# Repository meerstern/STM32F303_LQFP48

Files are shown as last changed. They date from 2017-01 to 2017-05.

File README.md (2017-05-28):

# STM32F303_LQFP48

The Converter board of Kicad Files for STM32F303-LQFP48

STM32F303 LQFP48を2.54mmピッチへ変換します。  
5列両側の一般的なブレッドボードで両側に1つ空きが出るサイズです。  
Nucleo等の評価ボードが発売されていない48ピンICの変換基板です。  
32ピンではRAMサイズやピン数が足りないが、64ピンでは多すぎるという方にお勧めです。  
※mbedには対応していません。 

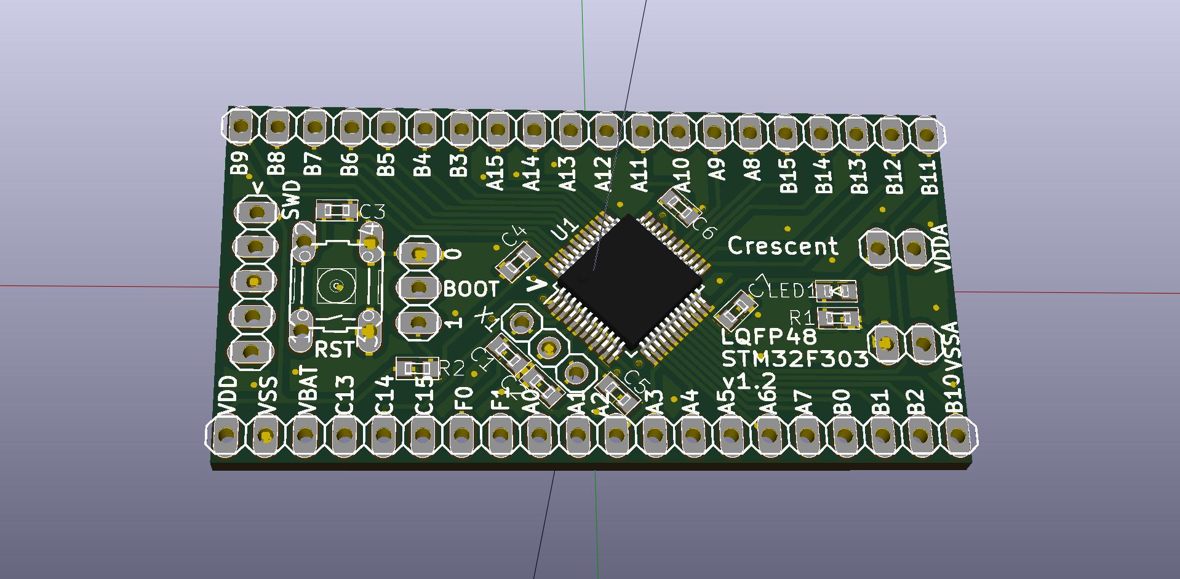
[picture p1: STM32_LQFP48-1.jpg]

 
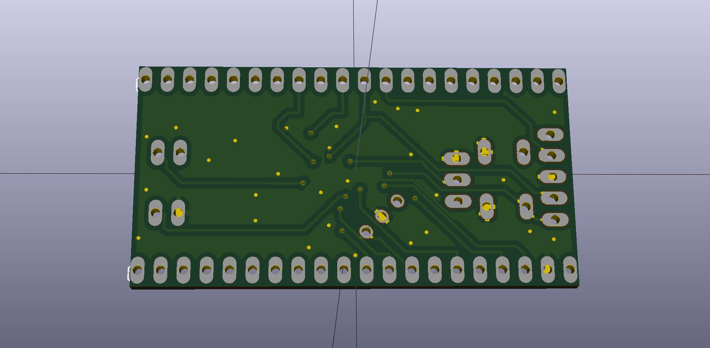
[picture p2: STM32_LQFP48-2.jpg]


## 仕様
  * MPU48ピンの全ピンにアクセス可能です。
  * 両側それぞれ20ピン、計40ピンです。
  * VDD及びVDDはそれぞれ1つのピンにまとめています。
  * アナログピンはVSSA、VDDAをジャンパするとVDDとVSSからそれぞれ供給されます。
  * VDDへ電源を供給するとLED1が点灯します。
  * SWDピンが出ているため、STLinkで接続して書き込みします。
  * SWDピンはNucleo等のSTLinkのピン配置と同じ順序です。
  * BOOT0のピンヘッダがあり、簡単にモード切り替え可能です。
  * タクトスイッチを取り付けることでリセットボタンが実装可能です。

## 使用可能MPU
  * STM32F303C8XX ROM64KB,  RAM12KB  [Digikey Link][1]
  * STM32F303CCXX ROM256KB, RAM40KB  [Digikey Link][3]
  ※上記の全MPUで動作確認している訳ではありません。  

[1]: http://www.digikey.jp/product-detail/ja/stmicroelectronics/STM32F303C8T6/497-15198-ND/5051326 "*1"
[3]: http://www.digikey.jp/product-detail/ja/stmicroelectronics/STM32F303CCT6/497-13318-ND/3660423 "*3"

## 書き込み方法/使用方法
  * アナログピンはVSSA、VDDAをジャンパさせます。
  * BOOTピンを0へセットします。
  * SWDピンが出ているため、STLinkで接続して書き込みします。
  * SWDピンはNucleo等のSTLinkのピン配置と同じ順序です。
  * 電源を供給し、NucleoやSTLinkV2プログラマ等を使用してSTLinkUtility等から書き込んでください。  
  
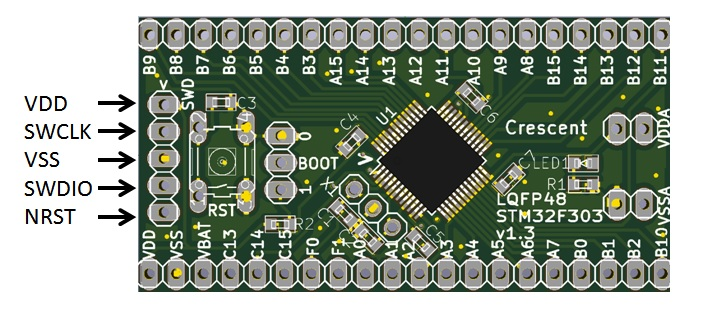
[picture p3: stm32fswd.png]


License - MIT

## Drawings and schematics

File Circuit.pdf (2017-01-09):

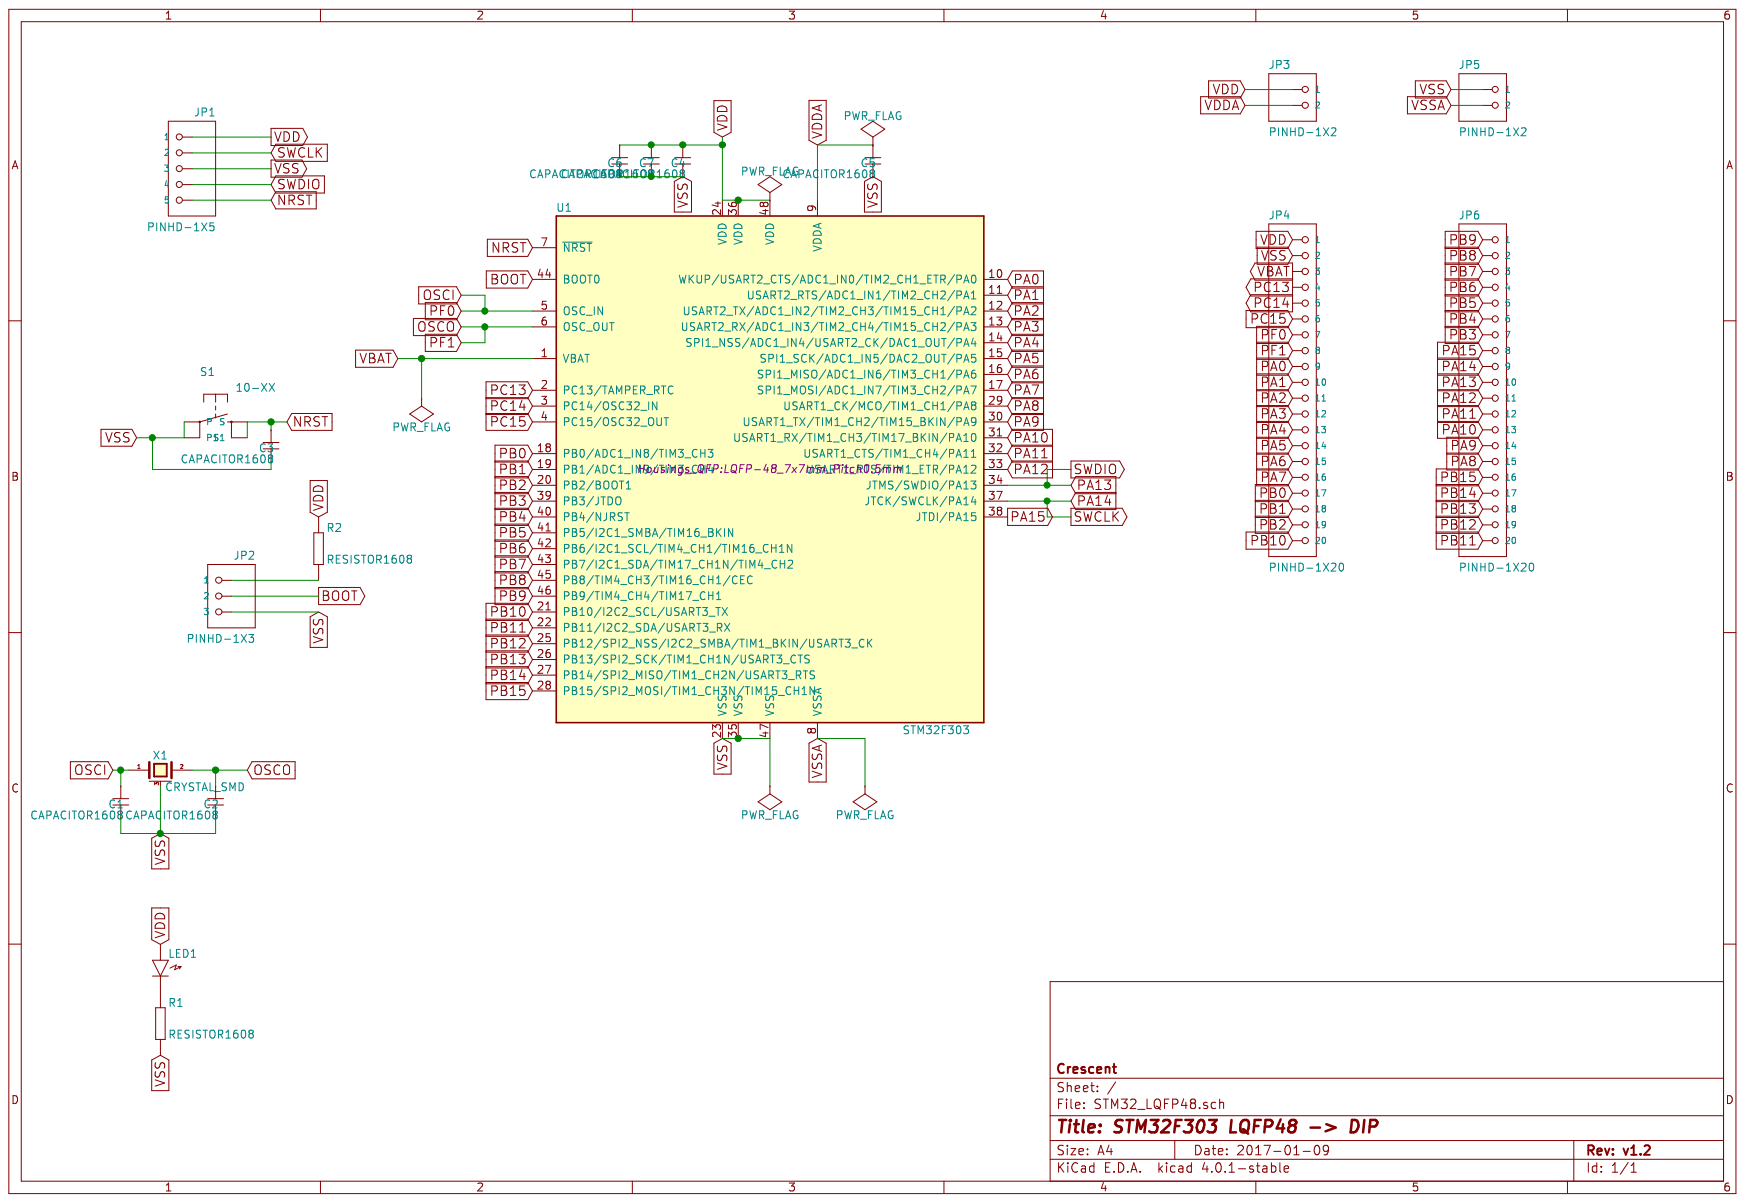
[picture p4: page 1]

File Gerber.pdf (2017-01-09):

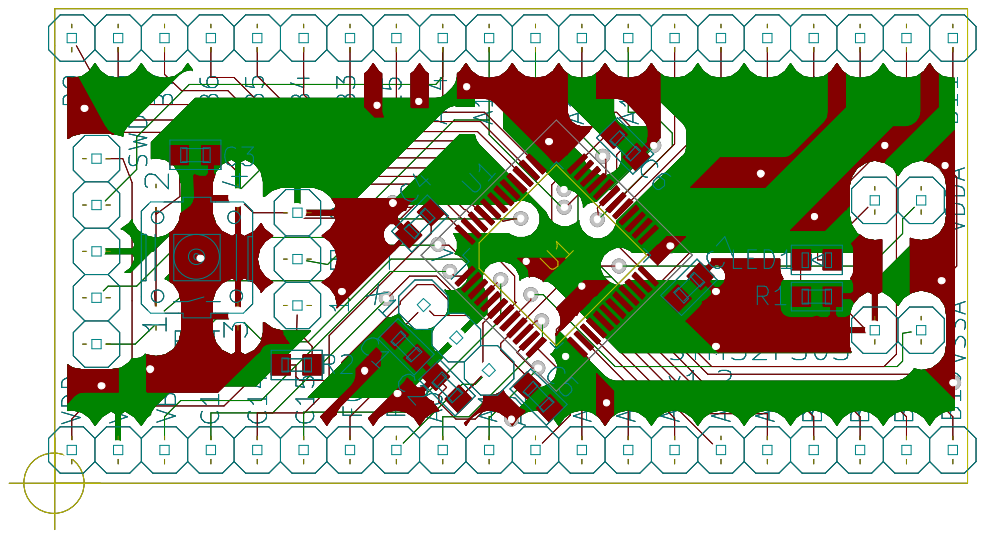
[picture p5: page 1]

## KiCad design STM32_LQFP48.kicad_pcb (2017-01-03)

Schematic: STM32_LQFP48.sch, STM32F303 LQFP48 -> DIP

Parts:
C1, C2, C3, C4, C5, C6, C7: CAPACITOR1608; generic-SMD1608
JP1: PINHD-1X5; pinhead-1X05
JP2: PINHD-1X3; pinhead-1X03
JP3, JP5: PINHD-1X2; pinhead-1X02
JP4, JP6: PINHD-1X20; pinhead-1X20
LED1: LED1608; generic-LED1608
R1, R2: RESISTOR1608; generic-SMD1608
S1: 10-XX; switch-omron-B3F-10XX
U1: STM32F303; LQFP-48_7x7mm_Pitch0.5mm
X1: CRYSTAL_SMD; pinhead-1X03

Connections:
BOOT: JP2.2, U1.44 (BOOT0)
NRST: C3.1, JP1.5, S1.1, S1.2, U1.7 (~NRST)
unnamed: JP2.1, R2.2
unnamed: LED1.K, R1.1
OSCI: C1.1, JP4.7, U1.5 (OSC_IN), X1.1
OSCO: C2.1, JP4.8, U1.6 (OSC_OUT), X1.2
PA0: JP4.9, U1.10 (WKUP/USART2_CTS/ADC1_IN0/TIM2_CH1_ETR/P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)
PA1: JP4.10, U1.11 (USART2_RTS/ADC1_IN1/TIM2_CH2/PA1)
PA2: JP4.11, U1.12 (USART2_TX/ADC1_IN2/TIM2_CH3/TIM15_CH1/P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)
PA3: JP4.12, U1.13 (USART2_RX/ADC1_IN3/TIM2_CH4/TIM15_CH2/P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)
PA4: JP4.13, U1.14 (SPI1_NSS/ADC1_IN4/USART2_CK/DAC1_OUT/PA4)
PA5: JP4.14, U1.15 (SPI1_SCK/ADC1_IN5/DAC2_OUT/PA5)
PA6: JP4.15, U1.16 (SPI1_MISO/ADC1_IN6/TIM3_CH1/PA6)
PA7: JP4.16, U1.17 (SPI1_MOSI/ADC1_IN7/TIM3_CH2/PA7)
PA8: JP6.15, U1.29 (USART1_CK/MCO/TIM1_CH1/PA8)
PA9: JP6.14, U1.30 (USART1_TX/TIM1_CH2/TIM15_BKIN/PA9)
PA10: JP6.13, U1.31 (USART1_RX/TIM1_CH3/TIM17_BKIN/PA10)
PA11: JP6.12, U1.32 (USART1_CTS/TIM1_CH4/PA11)
PA12: JP6.11, U1.33 (USART1_RTS/TIM1_ETR/PA12)
PA13: JP1.4, JP6.10, U1.34 (JTMS/SWDIO/PA13)
PA14: JP1.2, JP6.9, U1.37 (JTCK/SWCLK/PA14)
PA15: JP6.8, U1.38 (JTDI/PA15)
PB0: JP4.17, U1.18 (PB0/ADC1_IN8/TIM3_CH3)
PB1: JP4.18, U1.19 (PB1/ADC1_IN9/TIM3_CH4)
PB2: JP4.19, U1.20 (PB2/BOOT1)
PB3: JP6.7, U1.39 (PB3/JTDO)
PB4: JP6.6, U1.40 (PB4/NJRST)
PB5: JP6.5, U1.41 (PB5/I2C1_SMBA/TIM16_BKIN)
PB6: JP6.4, U1.42 (PB6/I2C1_SCL/TIM4_CH1/TIM16_CH1N)
PB7: JP6.3, U1.43 (PB7/I2C1_SDA/TIM17_CH1N/TIM4_CH2)
PB8: JP6.2, U1.45 (PB8/TIM4_CH3/TIM16_CH1/CEC)
PB9: JP6.1, U1.46 (PB9/TIM4_CH4/TIM17_CH1)
PB10: JP4.20, U1.21 (PB10/I2C2_SCL/USART3_TX)
PB11: JP6.20, U1.22 (PB11/I2C2_SDA/USART3_RX)
PB12: JP6.19, U1.25 (PB12/SPI2_NSS/I2C2_SMBA/TIM1_BKIN/USART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)
PB13: JP6.18, U1.26 (PB13/SPI2_SCK/TIM1_CH1N/USART3_CTS)
PB14: JP6.17, U1.27 (PB14/SPI2_MISO/TIM1_CH2N/USART3_RTS)
PB15: JP6.16, U1.28 (PB15/SPI2_MOSI/TIM1_CH3N/TIM15_CH1N)
PC13: JP4.4, U1.2 (PC13/TAMPER_RTC)
PC14: JP4.5, U1.3 (PC14/OSC32_IN)
PC15: JP4.6, U1.4 (PC15/OSC32_OUT)
VBAT: JP4.3, U1.1 (VBAT)
VDD: C4.1, C6.1, C7.1, JP1.1, JP3.1, JP4.1, LED1.A, R2.1, U1.24 (VDD), U1.36 (VDD), U1.48 (VDD)
VDDA: C5.1, JP3.2, U1.9 (VDDA)
VSS: C1.2, C2.2, C3.2, C4.2, C5.2, C6.2, C7.2, JP1.3, JP2.3, JP4.2, JP5.1, R1.2, S1.3, S1.4, U1.23 (VSS), U1.35 (VSS), U1.47 (VSS), X1.3
VSSA: JP5.2, U1.8 (VSSA)

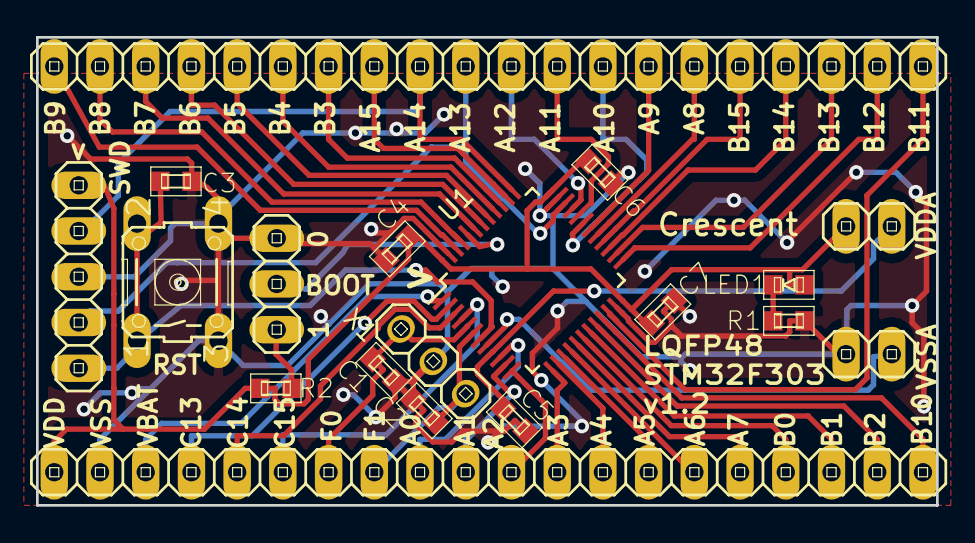
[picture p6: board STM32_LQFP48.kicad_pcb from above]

Board: 2 copper layers, 50.0 x 26.0 mm, 19 parts (0 on the bottom side), 46 nets.
